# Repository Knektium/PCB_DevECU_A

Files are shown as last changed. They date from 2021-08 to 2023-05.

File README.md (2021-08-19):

Wolley DevECU A
===============

This is the KiCad project for the PCB for the Wolley development ECU, DevECU A.

It has an Infineon XMC1404 MCU with buffered and ESD protected GPIO.

Specifications
--------------

| Name | Value |
| --- | ----- |
| PCB layers | 2 |
| Control Interface | CAN |

Key Components
--------------

| Component | Part | Details |
| ---| ---- | ---|
| MCU | Infineon XMC1404_F064X200A | ARM Cortex-M0, 32-bit, 48 MHz, 200 kB flash |
| CAN transceiver | Infineon TLE7251VSJ | |

Licence
-------

Licenced under the CERN Open Hardware Licence v1.2.

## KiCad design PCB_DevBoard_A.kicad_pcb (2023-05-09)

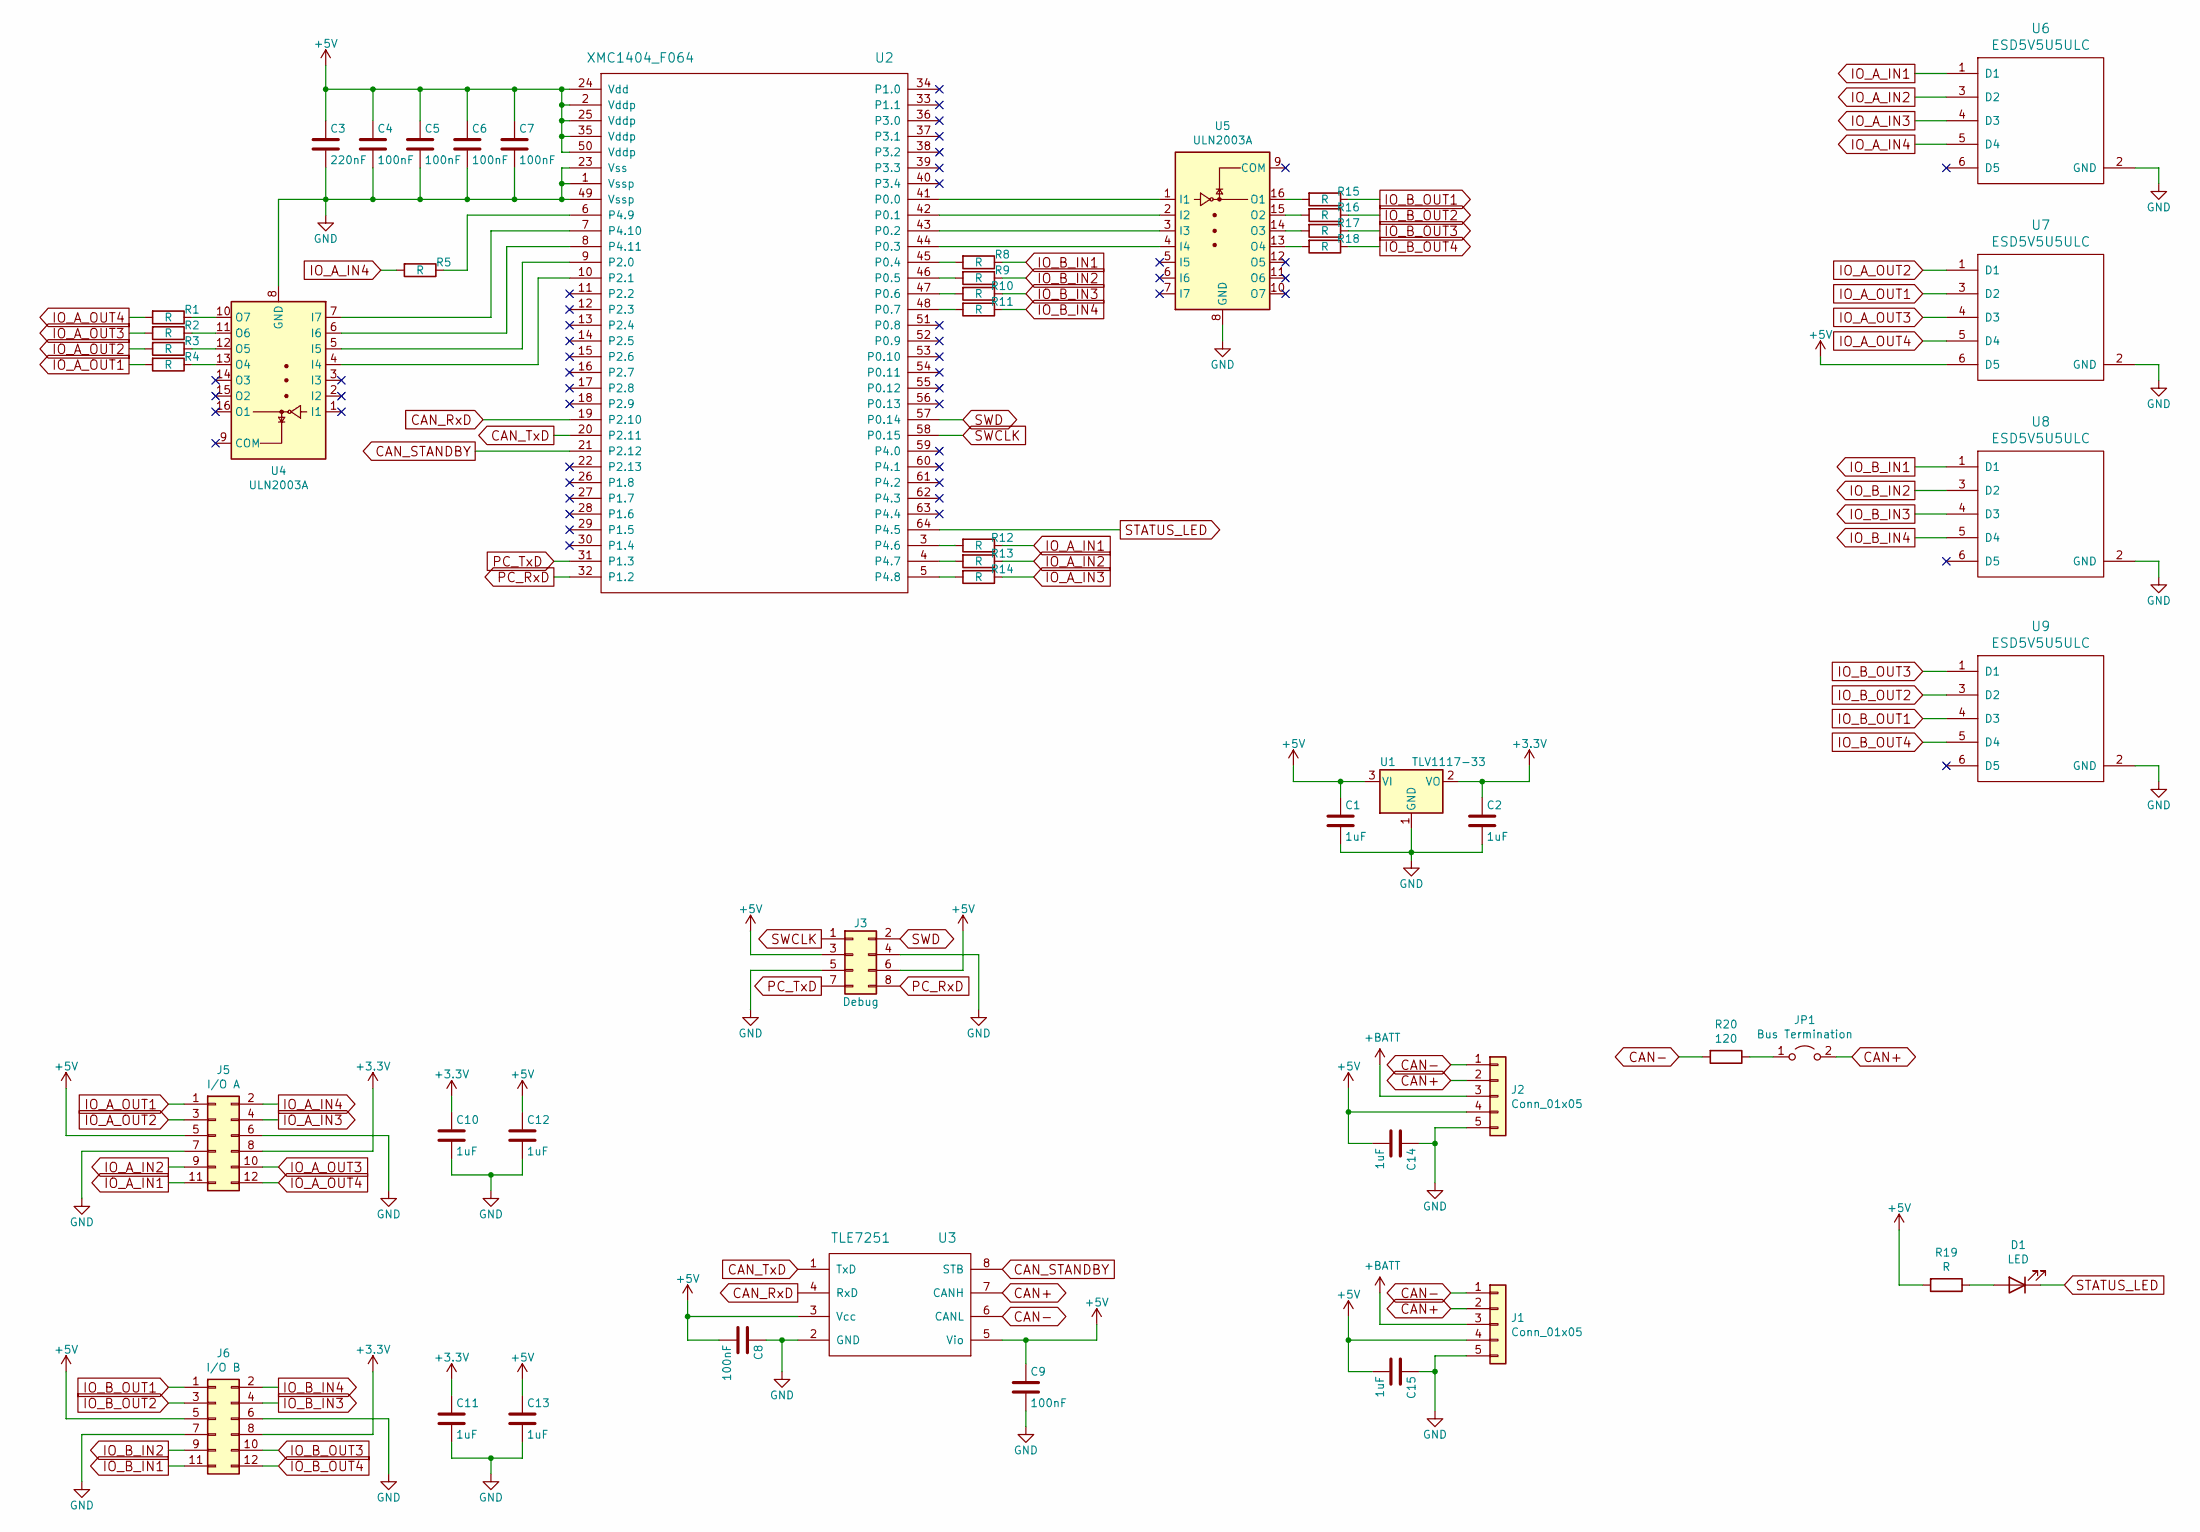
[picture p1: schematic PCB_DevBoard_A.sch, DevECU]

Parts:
C1, C2, C10, C11, C12, C13, C14: 1uF; C_0805_HandSoldering
C3: 220nF; C_0805_HandSoldering
C4, C5, C6, C7, C8, C9: 100nF; C_0805_HandSoldering
C15: 1uF; C_0805_2012Metric_Pad1.18x1.45mm_HandSolder
D1: LED; D_0805
J1, J2: Conn_01x05; WolleyInterconnect_THT_Angeled
J3: Debug; Pin_Header_Straight_2x04_Pitch2.54mm_SMD
J5: I/O A; Pin_Header_Angled_2x06_Pitch2.54mm
J6: I/O B; Pin_Header_Angled_2x06_Pitch2.54mm
JP1: Bus Termination; PinHeader_1x02_P2.54mm_Vertical
R1, R2, R3, R4, R5, R8, R9, R10, R11, R12, R13, R14, R15, R16, R17, R18, R19: R; R_0805_HandSoldering
R20: 120; R_0805_HandSoldering
U1: TLV1117-33; SOT-223-3_TabPin2
U2: XMC1404_F064; TQFP-64_10x10mm_Pitch0.5mm_Handsoldering
U3: TLE7251; SOIC-8_3.9x4.9mm_Pitch1.27mm
U4, U5: ULN2003A; SOIC-16_3.9x9.9mm_Pitch1.27mm
U6, U7, U8, U9: ESD5V5U5ULC; TSOP-6_1.65x3.05mm_Pitch0.95mm

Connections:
+3V3: C2.1, C10.1, C11.1, J5.8, J6.8, U1.2 (VO)
+BATT: J1.3, J2.3
CAN+: J1.2, J2.2, JP1.2 (B), U3.7 (CANH)
CAN-: J1.1, J2.1, R20.2, U3.6 (CANL)
CAN_RxD: U2.19 (P2.10), U3.4 (RxD)
CAN_STANDBY: U2.21 (P2.12), U3.8 (STB)
CAN_TxD: U2.20 (P2.11), U3.1 (TxD)
IO_A_IN1: J5.11, R12.1, U6.1 (D1)
IO_A_IN2: J5.9, R13.1, U6.3 (D2)
IO_A_IN3: J5.4, R14.1, U6.4 (D3)
IO_A_IN4: J5.2, R5.2, U6.5 (D4)
IO_A_OUT1: J5.1, R4.2, U7.3 (D2)
IO_A_OUT2: J5.3, R3.2, U7.1 (D1)
IO_A_OUT3: J5.10, R2.2, U7.4 (D3)
IO_A_OUT4: J5.12, R1.2, U7.5 (D4)
IO_B_IN1: J6.11, R8.1, U8.1 (D1)
IO_B_IN2: J6.9, R9.1, U8.3 (D2)
IO_B_IN3: J6.4, R10.1, U8.4 (D3)
IO_B_IN4: J6.2, R11.1, U8.5 (D4)
IO_B_OUT1: J6.1, R15.1, U9.4 (D3)
IO_B_OUT2: J6.3, R16.1, U9.3 (D2)
IO_B_OUT3: J6.10, R17.1, U9.1 (D1)
IO_B_OUT4: J6.12, R18.1, U9.5 (D4)
unnamed: D1.2 (A), R19.1
unnamed: JP1.1 (A), R20.1
unnamed: R1.1, U4.10 (O7)
unnamed: R2.1, U4.11 (O6)
unnamed: R3.1, U4.12 (O5)
unnamed: R4.1, U4.13 (O4)
unnamed: R5.1, U2.6 (P4.9)
unnamed: R8.2, U2.45 (P0.4)
unnamed: R9.2, U2.46 (P0.5)
unnamed: R10.2, U2.47 (P0.6)
unnamed: R11.2, U2.48 (P0.7)
unnamed: R12.2, U2.3 (P4.6)
unnamed: R13.2, U2.4 (P4.7)
unnamed: R14.2, U2.5 (P4.8)
unnamed: R15.2, U5.16 (O1)
unnamed: R16.2, U5.15 (O2)
unnamed: R17.2, U5.14 (O3)
unnamed: R18.2, U5.13 (O4)
unnamed: U2.7 (P4.10), U4.7 (I7)
unnamed: U2.8 (P4.11), U4.6 (I6)
unnamed: U2.9 (P2.0), U4.5 (I5)
unnamed: U2.10 (P2.1), U4.4 (I4)
unnamed: U2.41 (P0.0), U5.1 (I1)
unnamed: U2.42 (P0.1), U5.2 (I2)
unnamed: U2.43 (P0.2), U5.3 (I3)
unnamed: U2.44 (P0.3), U5.4 (I4)
PC_RxD: J3.8, U2.32 (P1.2)
PC_TxD: J3.7, U2.31 (P1.3)
STATUS_LED: D1.1 (K), U2.64 (P4.5)
SWCLK: J3.1, U2.58 (P0.15)
SWD: J3.2, U2.57 (P0.14)

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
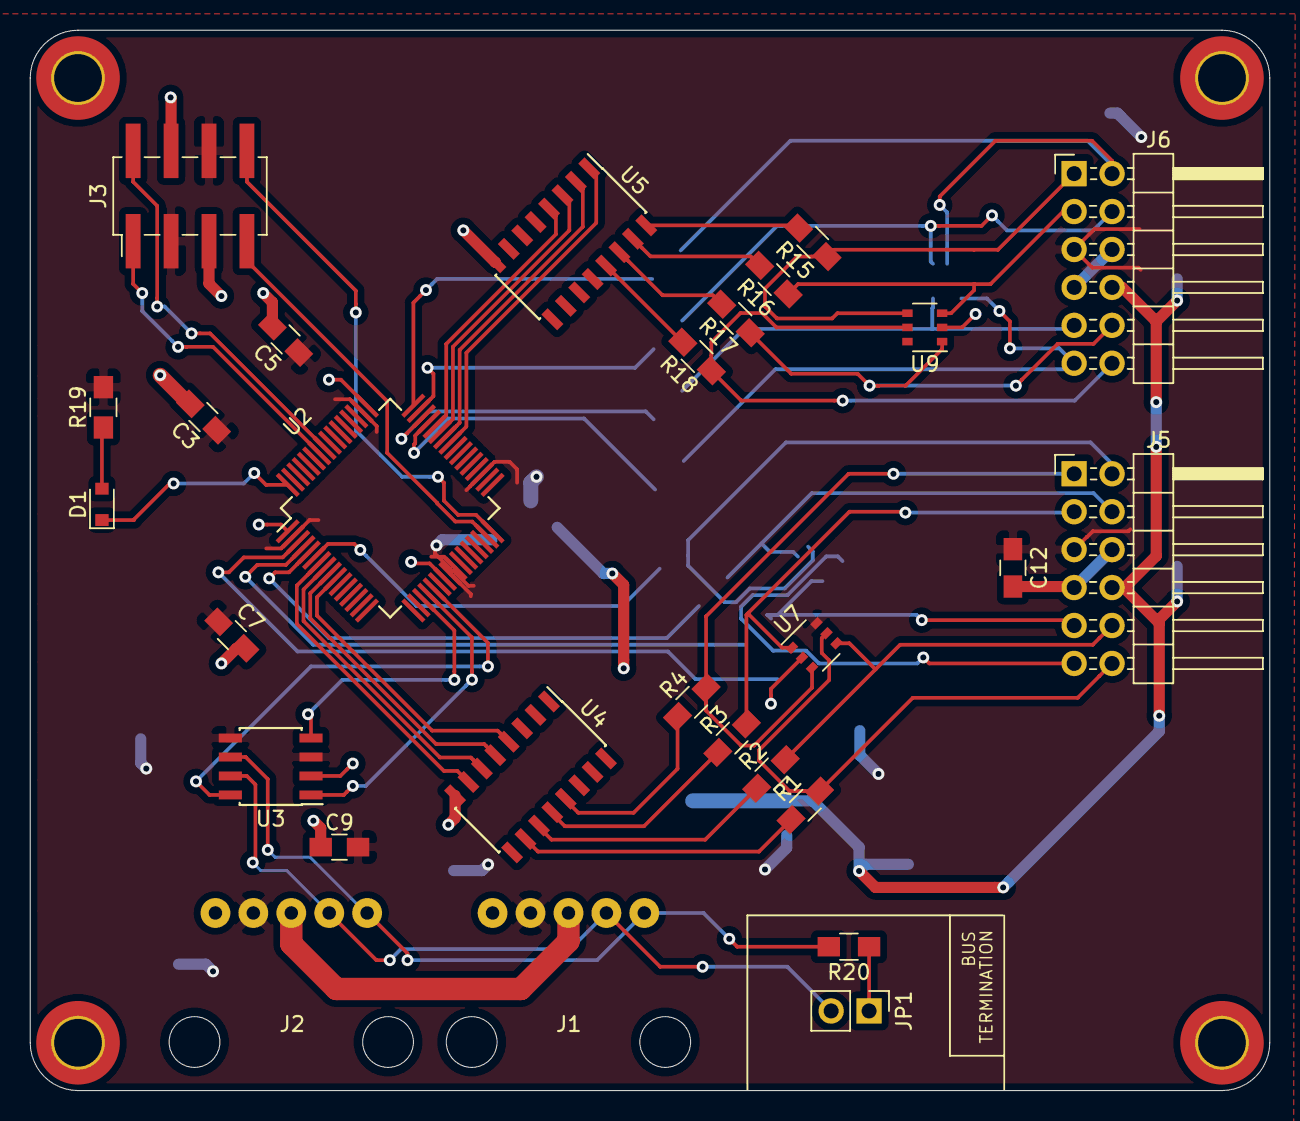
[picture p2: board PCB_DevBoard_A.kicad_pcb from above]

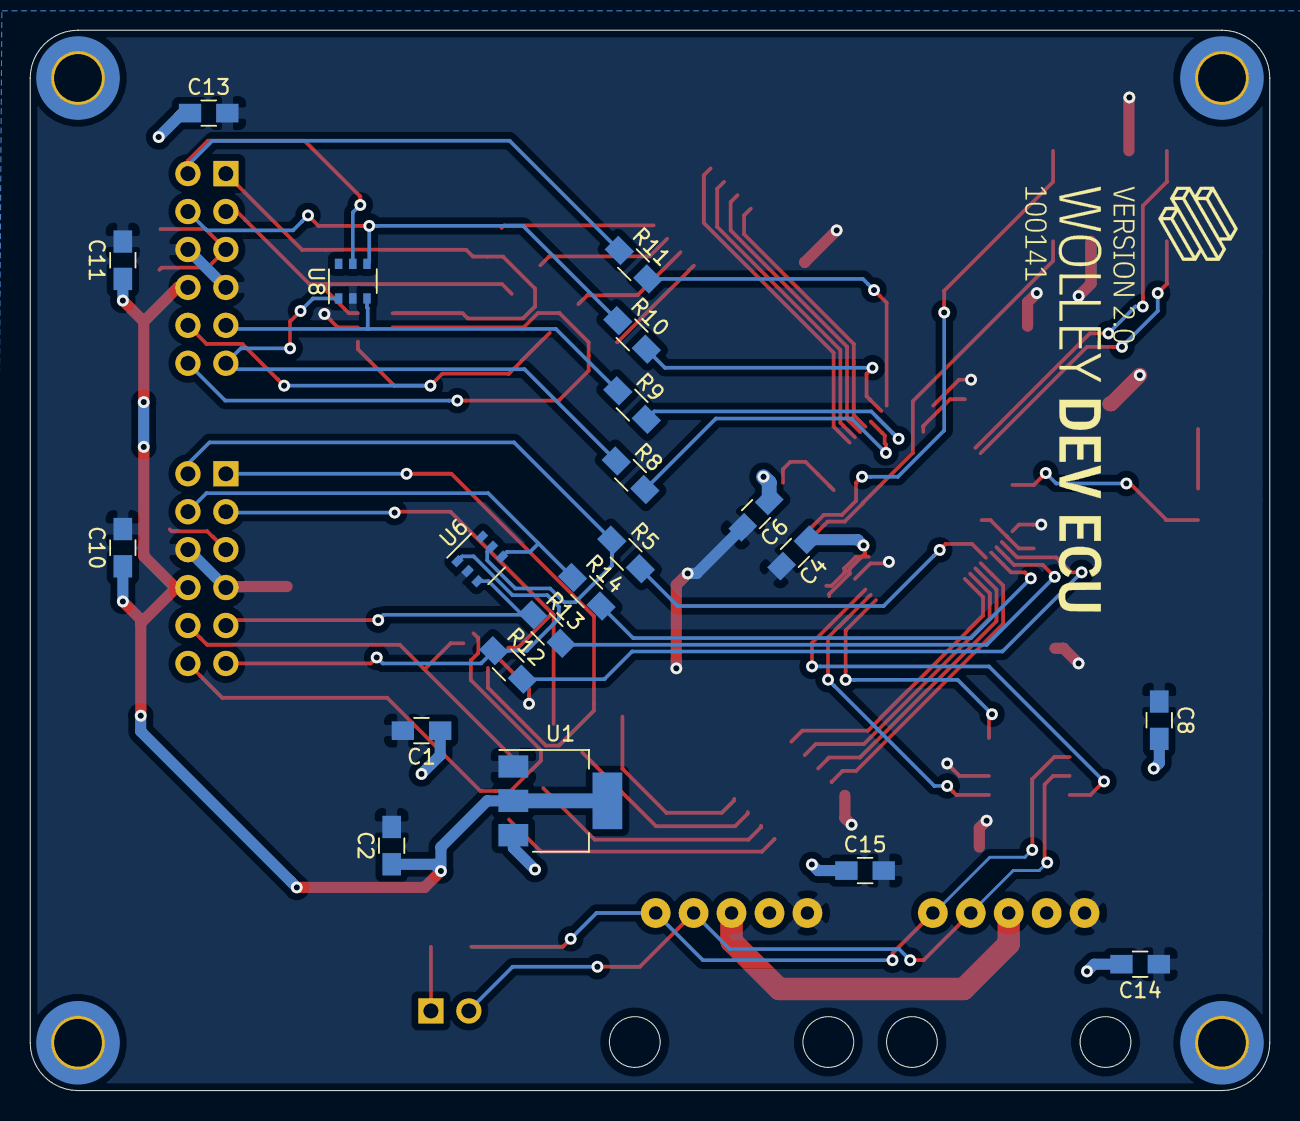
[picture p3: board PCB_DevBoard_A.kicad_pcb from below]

Board: 2 copper layers, 83.0 x 71.0 mm, 49 parts (21 on the bottom side), 56 nets.

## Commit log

2023-03-05 Change the Wolley connectors to the new 5-pin one
    [PCB_DevBoard_A.kicad_pcb, PCB_DevBoard_A.sch]
2023-03-05 Replace the termination switch with a jumper
    [PCB_DevBoard_A.kicad_pcb, PCB_DevBoard_A.sch]
2023-05-06 Move some capacitors to a better location
    [PCB_DevBoard_A.kicad_pcb]
2023-05-06 Improve the tracks between the connectors
    [PCB_DevBoard_A.kicad_pcb]
2023-05-06 Remove the ground vias around the edges
    [PCB_DevBoard_A.kicad_pcb]
2023-05-06 Update logotypes etc.
    [PCB_DevBoard_A.kicad_pcb]
2023-05-06 Replace the M2.5 mounting holes with M3 holes
    [PCB_DevBoard_A.kicad_pcb]
2023-05-09 Update document info
    [PCB_DevBoard_A.kicad_pcb, PCB_DevBoard_A.sch]
